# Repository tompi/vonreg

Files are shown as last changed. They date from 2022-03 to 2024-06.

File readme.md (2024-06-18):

# The Vonreg keyboard
---------------------

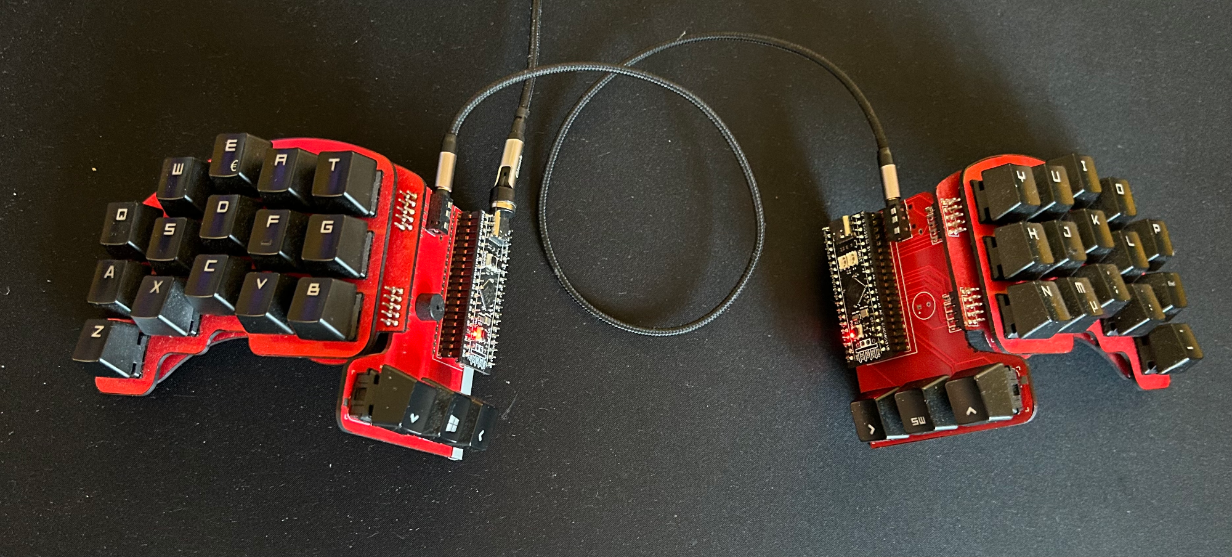
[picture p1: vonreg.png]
Vonreg


The Vonreg is an attempt at exploiting 3 dimensions with just pcb.
(vertical thumb cluster)

N.B: Although this board works fine, its a bit difficult to use,
since it will slide around, due to only 2 edges touching the table.

To build it you need to order pcbs, check out the releases.

You will also need the following parts:
2 x Blackpill MCU
2 x TRRS Jack
36 x MX switches and keycaps
4 x 2.54mm Double Row Right angle Male Breakaway PCB Board Pin Header Connector(2x5 pins)
1 x USB C cable
1 x TRRS cable (only need 3 poles)

Optional:
1 x Buzzer (4mm between pins)

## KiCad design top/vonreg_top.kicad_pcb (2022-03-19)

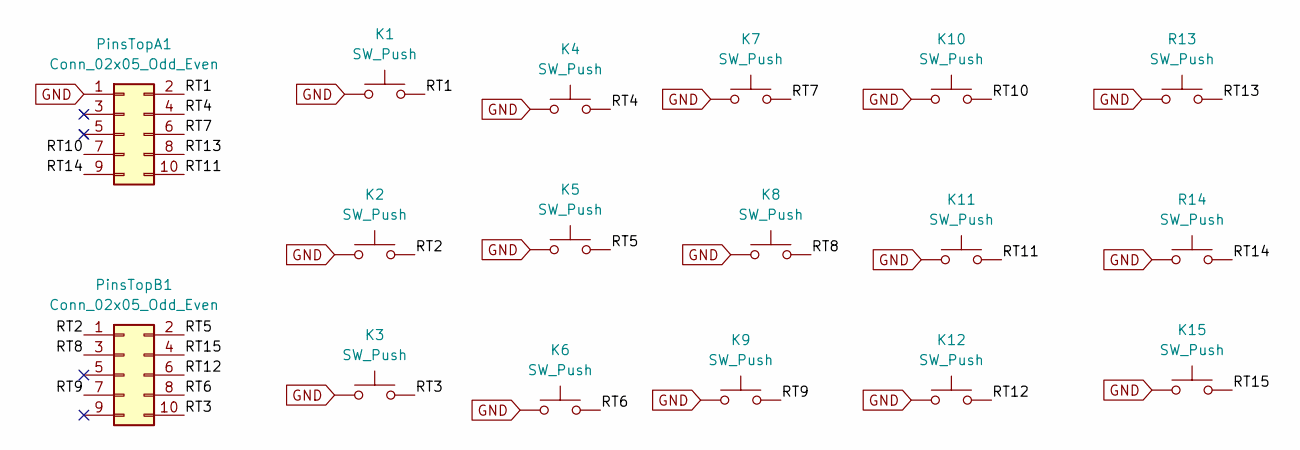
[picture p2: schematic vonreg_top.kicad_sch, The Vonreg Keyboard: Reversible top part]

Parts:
K1, K2, K3, K4, K5, K6, K7, K8, K9, K10, K11, K12, K15: SW_Push; Kailh_socket_MX_optional_reversible
PinsTopA1: Conn_02x05_Odd_Even; PinHeader_2x05_P2.54mm_Vertical
PinsTopB1: Conn_02x05_Odd_Even; PinHeader_2x05_P2.54mm_Vertical
R13, R14: SW_Push; Kailh_socket_MX_optional_reversible

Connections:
/RT1: K1.2, PinsTopA1.2
/RT2: K2.2, PinsTopB1.1
/RT3: K3.2, PinsTopB1.10
/RT4: K4.2, PinsTopA1.4
/RT5: K5.2, PinsTopB1.2
/RT6: K6.2, PinsTopB1.8
/RT7: K7.2, PinsTopA1.6
/RT8: K8.2, PinsTopB1.3
/RT9: K9.2, PinsTopB1.7
/RT10: K10.2, PinsTopA1.7
/RT11: K11.2, PinsTopA1.10
/RT12: K12.2, PinsTopB1.6
/RT13: PinsTopA1.8, R13.2
/RT14: PinsTopA1.9, R14.2
/RT15: K15.2, PinsTopB1.4
GND: K1.1, K2.1, K3.1, K4.1, K5.1, K6.1, K7.1, K8.1, K9.1, K10.1, K11.1, K12.1, K15.1, PinsTopA1.1, R13.1, R14.1

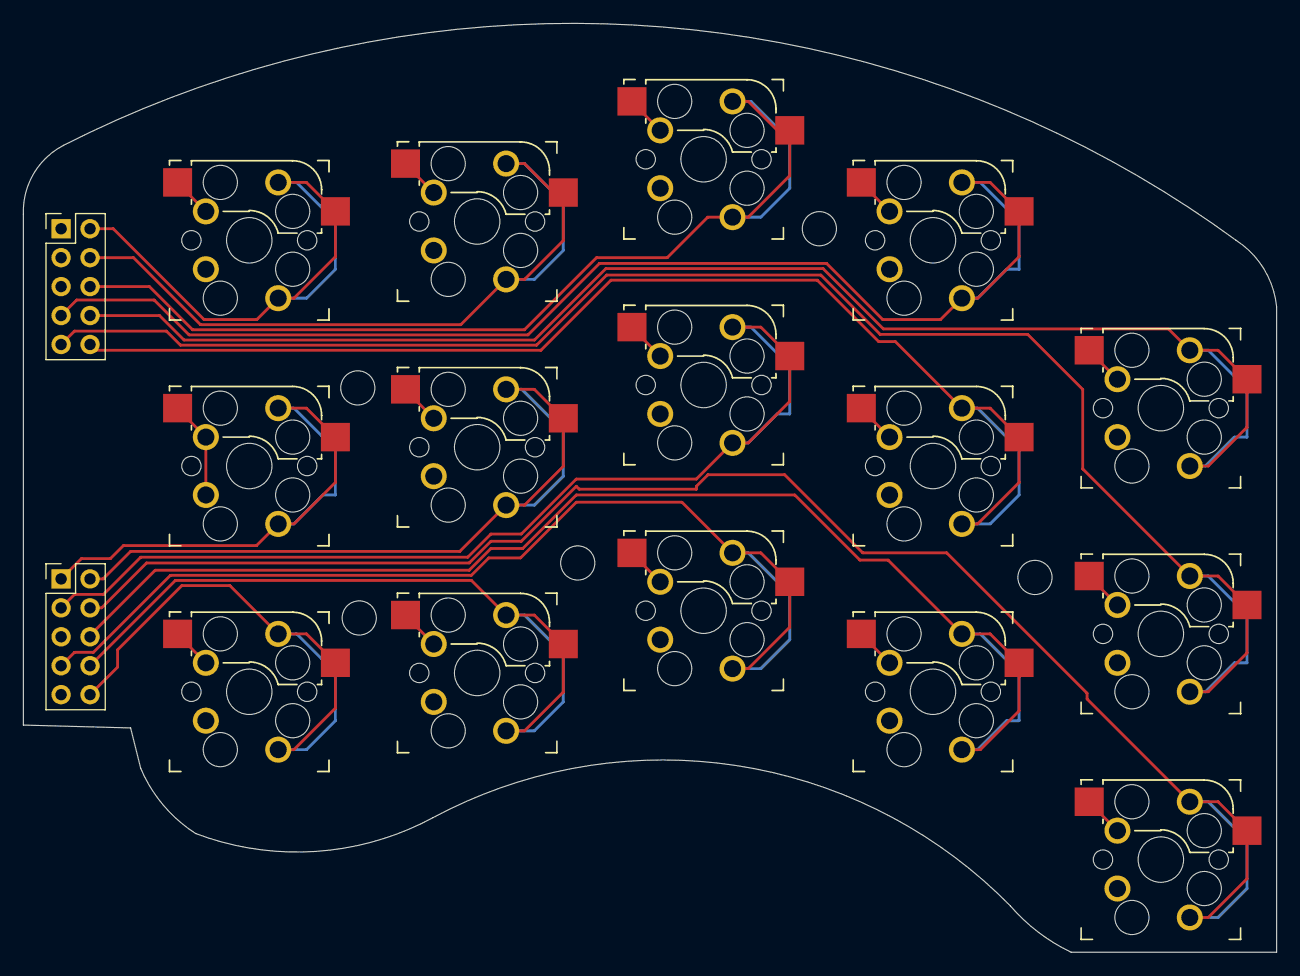
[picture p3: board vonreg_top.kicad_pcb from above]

Board: 2 copper layers, 110.0 x 81.5 mm, 22 parts (0 on the bottom side), 16 nets.

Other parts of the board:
H1, H1#2, H1#3, H1#4, H1#5: MountingHole_3mm

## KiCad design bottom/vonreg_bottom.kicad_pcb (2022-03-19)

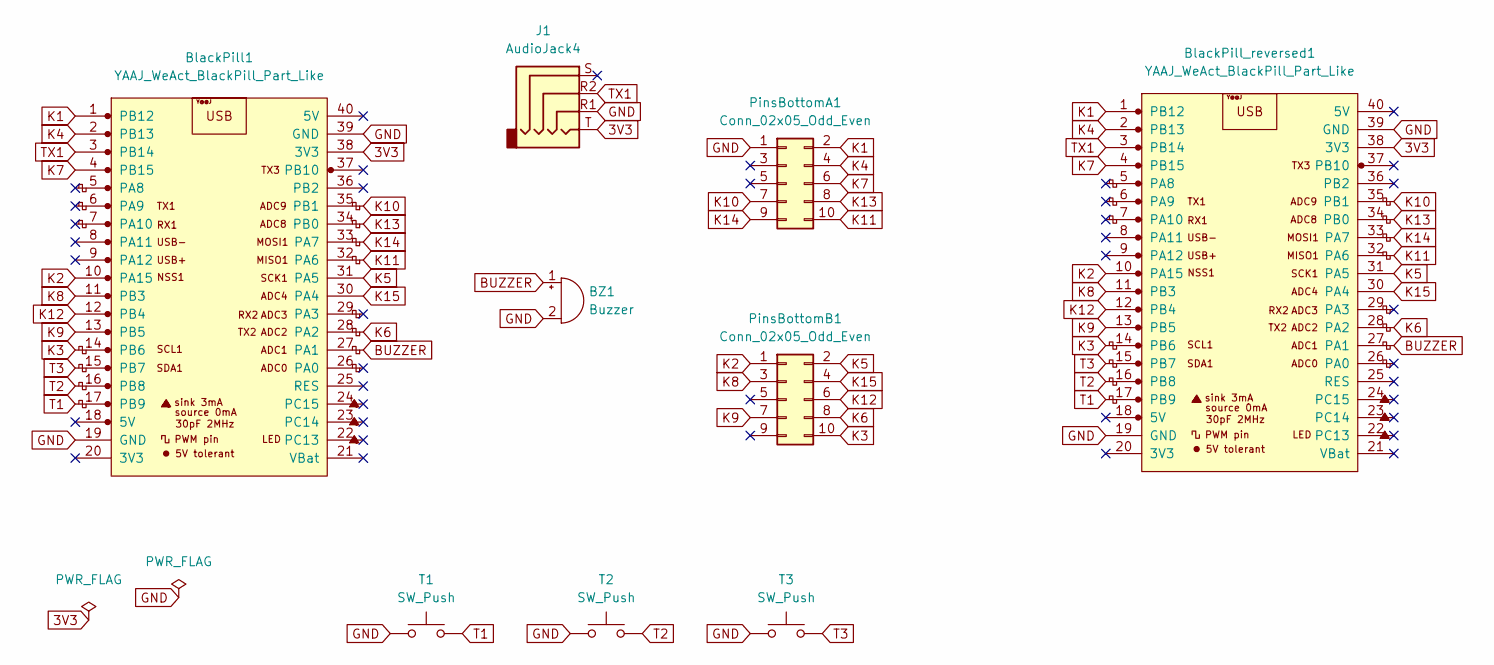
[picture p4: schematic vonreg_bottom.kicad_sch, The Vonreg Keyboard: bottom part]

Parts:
BZ1: Buzzer; MagneticBuzzer_PUI_AT-0927-TT-6-R
BlackPill1: YAAJ_WeAct_BlackPill_Part_Like; YAAJ_WeAct_BlackPill_2
BlackPill_reversed1: YAAJ_WeAct_BlackPill_Part_Like; YAAJ_WeAct_BlackPill_2
J1: AudioJack4; TRRS-PJ-320A-dual
PinsBottomA1: Conn_02x05_Odd_Even; PinHeader_2x05_P2.54mm_Vertical
PinsBottomB1: Conn_02x05_Odd_Even; PinHeader_2x05_P2.54mm_Vertical
T1, T2, T3: SW_Push; Kailh_socket_MX_optional_reversible

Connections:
3V3: BlackPill1.38 (3V3), BlackPill_reversed1.38 (3V3), J1.T
BUZZER: BZ1.1 (-), BlackPill1.27 (PA1), BlackPill_reversed1.27 (PA1)
GND: BZ1.2 (+), BlackPill1.19 (GND), BlackPill1.39 (GND), BlackPill_reversed1.19 (GND), BlackPill_reversed1.39 (GND), J1.R1, PinsBottomA1.1, T1.1, T2.1, T3.1
K1: BlackPill1.1 (PB12), BlackPill_reversed1.1 (PB12), PinsBottomA1.2
K2: BlackPill1.10 (PA15), BlackPill_reversed1.10 (PA15), PinsBottomB1.1
K3: BlackPill1.14 (PB6), BlackPill_reversed1.14 (PB6), PinsBottomB1.10
K4: BlackPill1.2 (PB13), BlackPill_reversed1.2 (PB13), PinsBottomA1.4
K5: BlackPill1.31 (PA5), BlackPill_reversed1.31 (PA5), PinsBottomB1.2
K6: BlackPill1.28 (PA2), BlackPill_reversed1.28 (PA2), PinsBottomB1.8
K7: BlackPill1.4 (PB15), BlackPill_reversed1.4 (PB15), PinsBottomA1.6
K8: BlackPill1.11 (PB3), BlackPill_reversed1.11 (PB3), PinsBottomB1.3
K9: BlackPill1.13 (PB5), BlackPill_reversed1.13 (PB5), PinsBottomB1.7
K10: BlackPill1.35 (PB1), BlackPill_reversed1.35 (PB1), PinsBottomA1.7
K11: BlackPill1.32 (PA6), BlackPill_reversed1.32 (PA6), PinsBottomA1.10
K12: BlackPill1.12 (PB4), BlackPill_reversed1.12 (PB4), PinsBottomB1.6
K13: BlackPill1.34 (PB0), BlackPill_reversed1.34 (PB0), PinsBottomA1.8
K14: BlackPill1.33 (PA7), BlackPill_reversed1.33 (PA7), PinsBottomA1.9
K15: BlackPill1.30 (PA4), BlackPill_reversed1.30 (PA4), PinsBottomB1.4
T1: BlackPill1.17 (PB9), BlackPill_reversed1.17 (PB9), T1.2
T2: BlackPill1.16 (PB8), BlackPill_reversed1.16 (PB8), T2.2
T3: BlackPill1.15 (PB7), BlackPill_reversed1.15 (PB7), T3.2
TX1: BlackPill1.3 (PB14), BlackPill_reversed1.3 (PB14), J1.R2

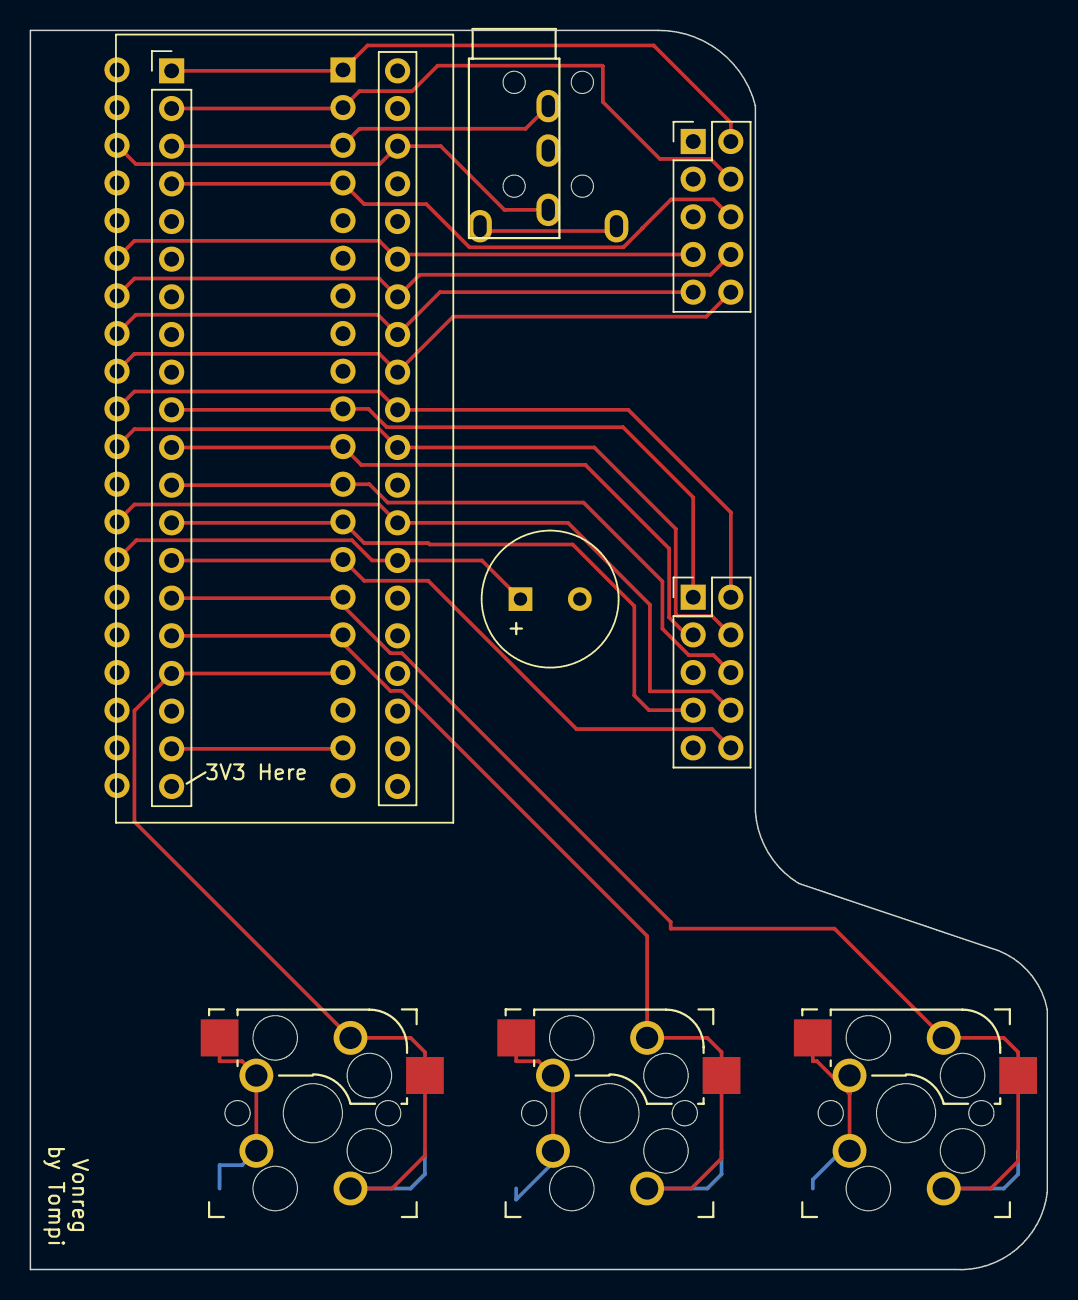
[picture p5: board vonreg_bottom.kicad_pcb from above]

Board: 2 copper layers, 68.6 x 83.6 mm, 9 parts (1 on the bottom side), 22 nets.

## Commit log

2022-03-07 Bottom passes ERC
    [vonreg_bottom.kicad_pcb, vonreg_bottom.kicad_sch, vonreg_top.kicad_pcb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]
2022-03-09 Aligned top/bottom
    [vonreg_bottom.kicad_pcb, vonreg_bottom.kicad_sch, vonreg_top.kicad_pcb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]
2022-03-12 Routing done, hopefully
    [vonreg_bottom.kicad_pcb, vonreg_bottom.kicad_sch, vonreg_top.kicad_pcb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]
2022-03-12 Rounded edge cuts
    [vonreg_bottom.kicad_pcb, vonreg_top.kicad_pcb]
2022-03-19 Ground pour and buzzer
    [vonreg_bottom.kicad_pcb, vonreg_bottom.kicad_sch, vonreg_top.kicad_pcb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]
2022-03-19 V1 ordered PCB
    [vonreg_bottom.kicad_pcb, vonreg_plate.kicad_pcb, vonreg_top.kicad_pcb]
2022-04-09 top plate: increase margins
    [vonreg_plate.kicad_pcb]
